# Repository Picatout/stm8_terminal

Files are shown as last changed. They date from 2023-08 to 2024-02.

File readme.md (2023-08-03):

# STM8 terminal 

Un terminal ASCII réalisé sur une carte NUCLEO-S207K8

*   Affichage 62 caractères par ligne, 25 lignes 
*   Clavier PS/2 
*   TVout NTSC. 
*   interface UART niveaux 0:5 volts 

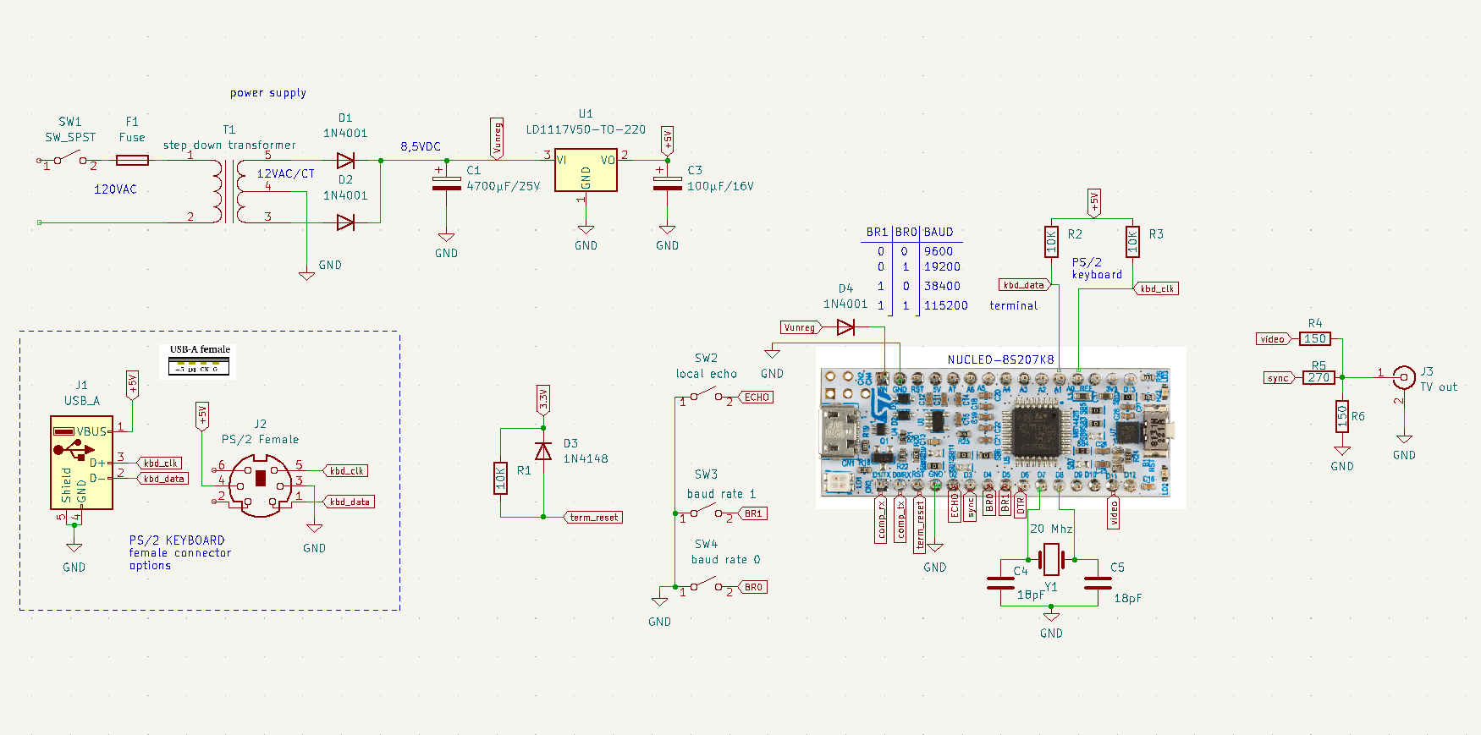
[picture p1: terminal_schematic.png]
schématique


Ce terminal a été créé pour le projet [POMME-I](https://github.com/Picatout/pomme-I).

Les 2 cartes NUCLEO-8S207K8 communique entre elle via le UART. Voir la schématique complète du projet [POMME-I](https://github.com/Picatout/pomme-I) sur le déppôt github de ce dernier. 

## Quand il faut compter les cycles machines.

Sortir 40 caractères par ligne avec un MCU fonctionnant à 20Mhz en utilisant le protocole NTSC n'a pa été évident. Il n'y avait tout simplement pas suffisamment de temps pour utiliser des compteurs avec boucle. Le temps d'affichage d'une ligne de balayage NTSC est de 52µsec. 1 cycle cpu à 20Mhz dure 50nsec on dispose donc d'un maximum de 1040 cycles pour afficher les 40 caractères ce qui donne 26 cycles cpu par caractère.

Après plusieurs expérimentation avec le périphérique SPI qui ne donnait pas de résultat satisfaisant j'ai abandonné le SPI. Pour y parvenir j'ai fait 2 choses. 

1. Le tampon video **video_buffer** ne contient pas les caractères à afficher mais l'adresse du caractère dans la table **font_6x8**. Ainsi il n'y a pas de cycle perdu pour faire le calcul de l'adresse du caractère pendant l'affichage. C'est la routine **tv_putc** qui fait le travail. 

1. Pour sortir les pixels vidéos il faut sérialiser les pixels représentant le caractère. Faire ça en sorftware prend 14 cycles cpu avec la macro  **_shift_out_char** du fichier [tvout.asm](tvout.asm).
La macro **_shift_out_scan_line** prend 20 cycles au total en incluant **_shift_out_char**. Si on fait le calcul pour 40 caractères ça fait 800 cycles soit 40µsec. Bien en déça des 52µsec allouée. Ça c'est selon les cycles machines fournis par le manufacturier du STM8 mais en pratique la durée mesurée à l'oscilloscope est de 51.2µsec. C'est serré! Tellement serré que je ne pouvait utiliser des boucles avec compteurs. Pour arriver à ce temps j'ai du dérouler la macro 40 fois. 

# Où sont passés ces cycles CPU. 

Je me suis mis à réfléchir à cette différence entre le nombre de cycles CPU selon ce que je mesure à l'oscilloscope le temps d'éxécution par caractère serait de 51.2µsec/50nsec=1024/40=25.6 cycles au lieu de 20 cycles. 5.6 de plus. Donc je me demandais où étaient passés ces cycles? Je me suis dit que le fait de lire l'octet dans la table font_6x8 entre en concurrence avec la lecture des instructions machine. STM8 est une architecture Harvard. Ça signigit que le bus d'instruction est séparé du bus de données. Cette architecture a étée conçue pour améliorer la vitesse d'exécution des instructions puisque celle-ci n'ont pas à partager l'accès mémoire avec les données. Je me suis donc dit que si je copiais la table [font_6x8](font.asm) dans la mémoire RAM ce conflit d'accès serait éliminé et que l'exécution serait plus rapide. 

J'ai fait le test et c'est bien le cas, sauf qu'il n'y a qu'un seul cycle machine par caractère de récupéré. L'affichage des 40 caractères avec la police en mémoire RAM prend 49.2µsec soit 2µsec de moins ce qui correspond une fois le calcul fait à 1 cycle par caractère. Il y a donc encore 4.6 cycles manquant. 

Pour comprendre cette différence il faut lire le chapitre 5 du manuel de progammation  [PM0044](https://www.st.com/content/ccc/resource/technical/document/programming_manual/43/24/13/9a/89/df/45/ed/CD00161709.pdf/files/CD00161709.pdf/jcr:content/translations/en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). La section 5.4 et la table 3 nous donnes un bel exemple. Selon le nombre de cycles données dans la description de chaque instruction: 

1.  LDW X,[$50.w] ; 5 cycles 
1.  ADDW X,#20   ; 2 cycles 
1.  LD A,[$300].w ; 4 cycles 

On obtient un total de **11 cycles**. mais dans la table 3 on voit qu'en fait il en faut **12**. 

Donc en conclusion le pipelining permet d'accélérer l'exécution des instructions sauf qu'il n'est plus possible de se fier au nombre de cycles donnés dans la description de chaque instruction pour calculer le temps d'exécution d'une séquence d'instructions, comme c'est le cas pour un mcu PIC 16Fxxxx. 

### 2023-07-17

L'intégration du **STM8_terminal** avec l'ordinateur **POMME-I** a nécessité des modifications aux 2 projets. Durant certaines opérations du terminal ce dernier perdait des caractères envoyés par l'ordinateur. Le problème a été corrigé par l'ajout d'un contrôle de flux matériel appellé **DTR** pour *Data Terminal Ready*. l'ordinateur n'envoie des caractères au terminal que lorsque ce signal est à **0** volt.

### 2023-07-05 

* Modification au circuit du terminal pour ajouter des commutateurs pour la sélection d'options utilisateur.

    * **SW3** sert à sélectionner un écho local lorsqu'il est à **1** 
    * **SW4** et **SW5** permettent de sélectionner un BAUD rate pour  le UART.

  SW4|SW5|BAUD 
    -|-|-
    0|0| 9600
    0|1| 19200
    1|0| 38400
    1|1| 115200

Si les commutateurs ne sont pas installés par défaut les broches sont toutes à **1** à travers les résistances *pull up* MCU, donc il y a écho local et le BAUD est à 115200.

Les commautateurs sont lu lors de l'initialisation et toute modification de leur position requiert un redémarrage du MCU pour que la nouvelle configuration prenne effet.

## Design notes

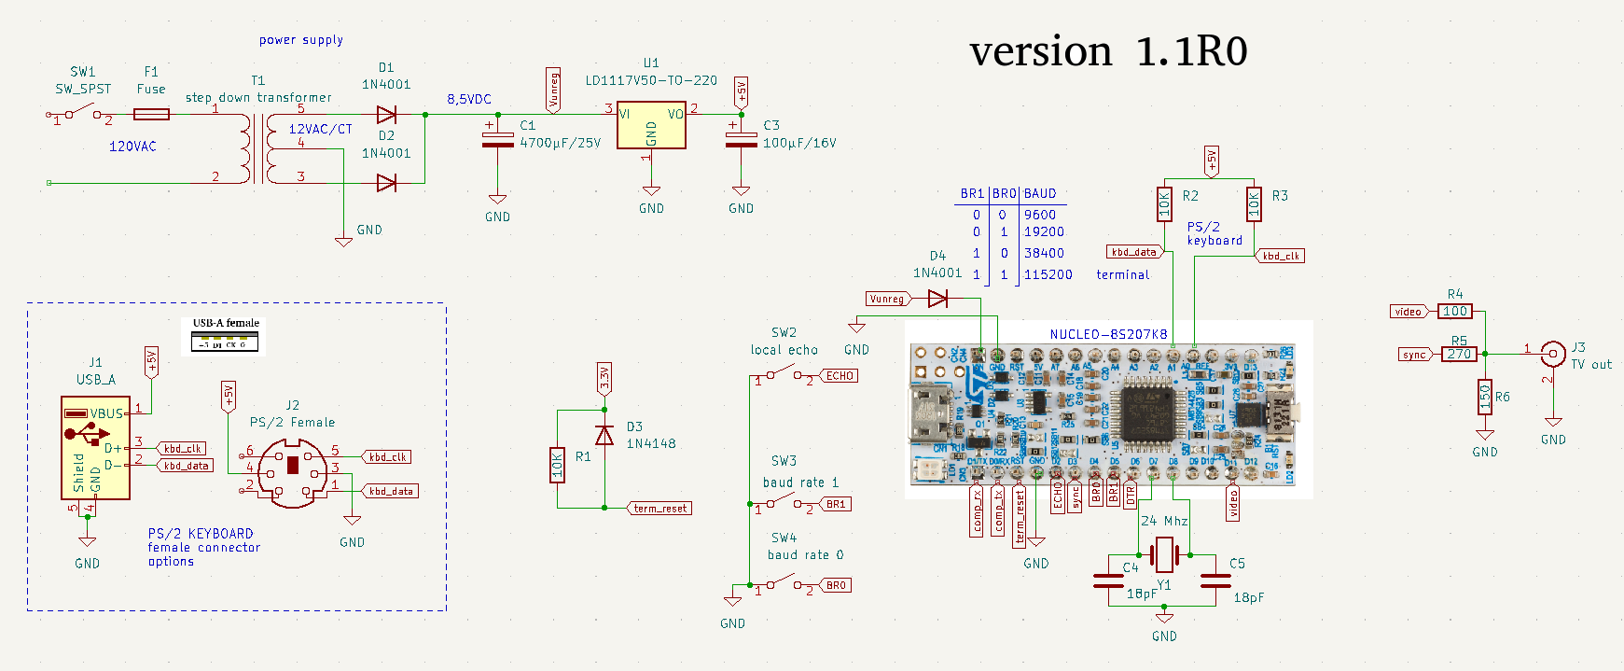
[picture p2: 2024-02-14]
terminal_schematic_v1.1r0.png

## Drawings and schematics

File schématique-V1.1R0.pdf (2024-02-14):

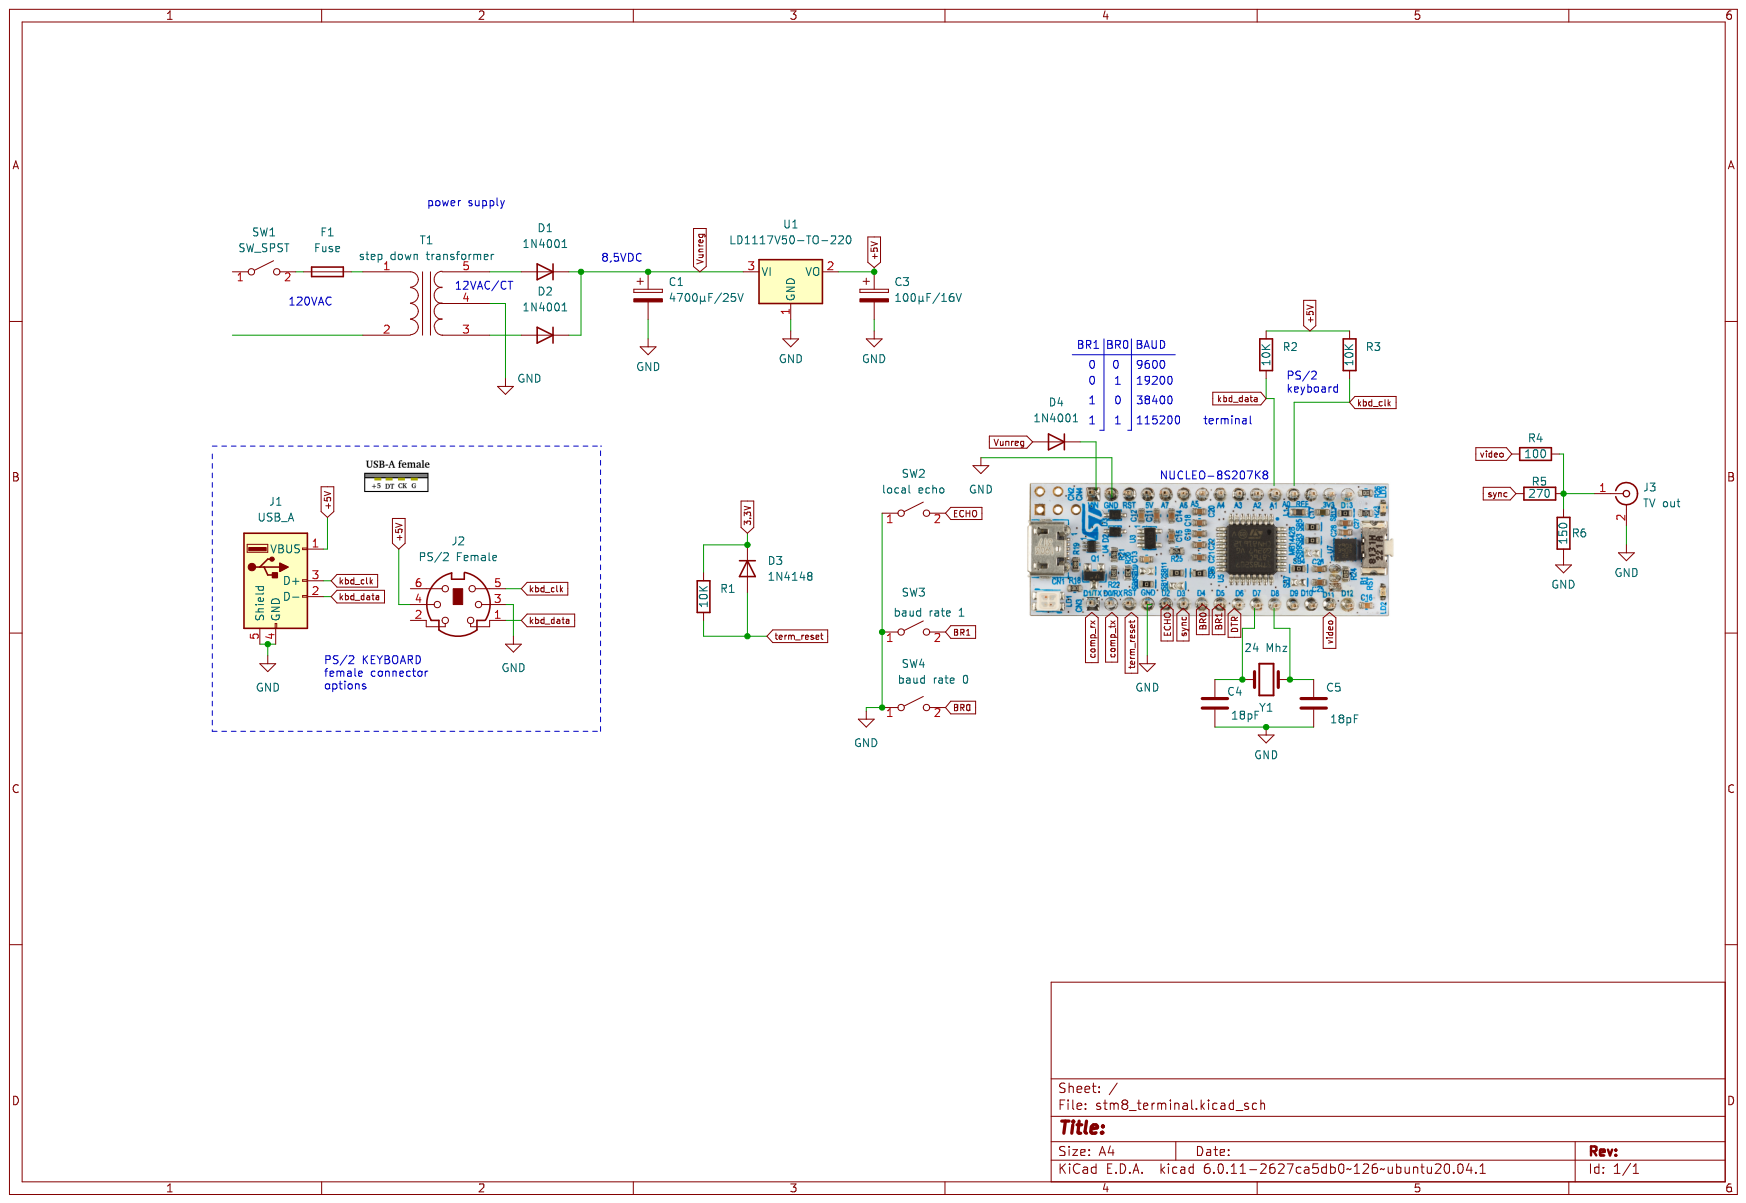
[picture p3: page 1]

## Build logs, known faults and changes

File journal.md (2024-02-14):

### 2024-02-14 

* Mise à jour version vers **V1.1R0**. 

* Modificaction au circuit. 
    1. Test ave crystal de 24Mhz, permet d'afficher 75 caractères par ligne. 
    1. Réduction de la valeur de la résistance **R4** à 100 ohm. 

* Simplifié routine **uart_init** dans [uart.asm](uart.asm).

### 2024-02-09 

* VERSIION **V1.0R15**

* Ajout de la routine **wait_state** pour reprogrammer **OPT7** car le cristal est à 20 Mhz il faut ajouté un wait state pour l'accès à la mémoire FLASH.

### 2023-12-30 

* L'interruption du TIMER4 utilisé pour contrôler le clignotement du curseur texte faisait trop d'interférence dans l'affichage vidéo. J'ai donc modifié le code qui maintenant utilise l'interruption du TIMER1 overflow pour contrôler le clignotement du curseur. 

### 2023-08-08

* Tag V1.0R13 

* Corrigé bogue perte de caractères lors d'un défilement vers le haut.

* Réécriture de la routie *tv_clear_line*. 

* Réécriture de *tv_cls**. Bloqué signal DTR pendant cette opération pour éliminer la perte de caractères en réception uart.

### 2023-08-06

* Corrigé bogue avec **CTRL+lettre** qui ne fonctionnait pas lorsque la touche Verr. Maj. était activée.

### 2023-08-05 

* V1.0R12 
    * Corrigé bogue **CTRL_lettre** ne fonctionnait pas lorsque le **verr.Maj** était activé.

* Modifié l'interface clavier pour que l'hôte puisse envoyer une commande au clavier afin de contrôler l'état des LEDs **Maj. lock** **Num. lock**.

### 2023-08-04

* Modifié le caractère soulignement dans le fichier [font.asm](font.asm).

### 2023-08-02

* V1.0R10 

* Ajout de la commande ANSI  **ESC[6n** qui renvoie la position du curseur sous la forme: **ESC[n;mR**

* Ajout de la commande d'application **ESC_V** pour demander au terminal d'imprimer la version de son firwmare.

### 2023-07-31

* V1.0R9  Ajout de la commande ANSI 
    * **ESC_ C** qui retourne le caractère à la position du curseur.

* Ajout des séquences de contrôle ANSI suivantes:
    * **ESC[ s**  pour sauvegarder la position actuelle du curseur.
    * **ESC[ u**  pour restaurer la position du curseur sauvegardée avec **ESC[ s**.

### 2023-07-29

* Ajout des séquences de contrôle ANSI suivantes:
    * ESC[ n A  déplace le curseur de *n* lignes vers le haut.
    * ESC[ n B  déplace le curseur de *n* lignes vers le bas.
    * ESC[ n C  déplace le curseur de *n* colonnes vers la droite.
    * ESC[ n D  déplace le curseur de *n' colonnes veres la gauche. 

Pour toutes ces commandes la valeur par défaut de *n' est **1**. Si le curseur est déjà à la limite la commande est ignorée.    

### 2023-07-22

* Révision 6 

* Modifié [tv_term.asm](tv_term.asm) pour que le caractère sous le curseur soit préservé.

* Modification à la routine *process_csi* du fichier [tv_term.asm](tv_term.asm). Le problème est le suivant, à l'interne les valeurs de position du curseur son comptée à partir de zéro alors que la commande **LOCATE** de **POMME BASIC** compte à partir de **1** comme les commandes ANSI. Il faut donc décrémenter la valeur des paramètres avant de les appliquer. Je n'avais pas tenu compte de ça dans la première écriture de la routine.

### 2023-07-21 

* Ajout des séquences de contrôle suivantes:
    * **ESC [ Pn G**  pour positionné le curseur sur la colonne **Pn** {1..62} 
    * **ESC [ Pn d**  pour positionner le curseur sur la ligne **Pn** {1..25}
    * **ESC [ Pn ; Pm H** pour positionner le curseur à la ligne **Pn** et la colonne **Pm**.

### 2023-07-17 

* L'intégration du **STM8_terminal** avec l'ordinateur **POMME-I** a nécessité des modifications aux 2 projets. Durant certaines opérations du terminal ce dernier perdait des caractères envoyés par l'ordinateur. Le problème a été corrigé par l'ajout d'un contrôle de flux matériel appellé **DTR** pour *Data Terminal Ready*. l'ordinateur n'envoie des caractères au terminal que lorsque ce signal est à **0** volt.

* Corrigé bogue dans routine *if_shifted* du fichier [ps2.asm](ps2.asm).

* Le terminal n'était pas assez rapide pour capturer tous les caractères reçus du UART. 
    * vitesse du UART réduite à 38400BAUD 
    * Ajout d'une sortie **DTR** sur la broche **D6** 
    * Augmentation de la file du UART à 64 charactères.
    * Augmentation de la file des scan codes à 16 octets.
    * mise à jour révision vers V1.0R2 
    
### 2023-07-10

* Nouvelle tentative d'urtiliser le périphérique SPI dans tvout.asm
    * Succès, même que le nombre de caractères affichable par ligne est passé à 64.
    * Les caractères s'affichent plus nettement, intensité plus régulière.

### 2023-07-05

* Modification de *uart_init* pour lire les switches SW4 et SW5 pour déterminer le BAUD requis.

* Modification de la routine *ntsc_init* pour copier la table *font_6x8* dans la RAM et vérifier l'état de SW3 pour l'écho local.

* Modification au circuit du terminal par l'ajout de commutateurs externes pour les options.

    * **SW3** sélection de l'écho local. 
        **0** pas d'écho locale 
        **1** échoe locale 

    * **SW5** et **SW5** sélection du BAUD rate du UART.

    SW4|SW5|BAUD 
    -|-|-
    0|0| 9600
    0|1| 19200
    1|0| 38400
    1|1| 115200

* Continuation du travail sur [ps2.asm](ps2.asm). 
    * installation de la police de caractères [font_6x8](font.asm) en mémoire RAM. Ceci permet de sauver 2µsec par scan line dans l'interruption d'affichage vidéo **ntsc_video_interrupt**.

    * Ajout du traitement pour les altérations de caractères du aux touches **CTRL** et **ALT**. Les touches de gauche et de droite sont traitées de la même façon.

    * Ajout de la commande **CTLR+E** pour commuter (toggle) l'écho local sur stm8_terminal. 

* mise à jour du [readme.md](readme.md).

### 2023-07-04

* Avancement du travail sur [ps2.asm](ps2.asm), traite les touches **Ver. maj.** et  **Maj.** correctement. Reste à implémentater le traitement des touches **CTRL** et **ALT**. 

* Travail sur [ps2.asm](ps2.asm).

### 2023-07-03 

* Début du travail sur [ps2.asm](ps2.asm).

* Corrigé bogue dans *tv_cursor_right*. 

* Corrigé bogue dans *tv_disable_cursor*. 

*  Travail sur [tvout.asm](tvout.asm), j'ai trouvé une méthode pour permettre d'afficher 40 caractères par ligne. Le tampon vidéo contient l'adresse du caractère dans la table de la police, plutôt que le caractère lui-même. De cette façon cette adresse n'a pas besoin d'être calculé au moment de l'affichage. On sauve ainsi plusieurs cycles machines par caractère. De plus l'espace entre chaque caractère est plus étroit ce qui améliore l'apparence.

### 2023-07-02

* Travail sur [tvout.asm](tvout.asm), amélioration au prix de la réduction du nombre de caractère par ligne 34 au lieu de 40. 

 * Abandon de l'utilisation du périphérique SPI. 

 * les pixels sont sérialisés avec déroulement des boucles en utilisant des macros. C'est la seule façon de réduire le nombre de cycles machine par pixel. Avec cette méthode j'obtient 28 cycles par pixel. 7 pixels par caractères sont envoyés.

### 2023-07-01

 * Ajout de [tv_term.asm](tv_term.asm). Encore un problème avec la qualité de l'affichage sur la tV.

 * Travail sur [tvout.asm](tvout.asm), maintenant affiche les caractères presque correctement sauf qu'il en affiche 41 par ligne au lieu d 40. 
 l'affichage ne semble pas tenir compte des scan_lines!!.

### 2023-06-29

* Travail sur [tvout.asm](tvout.asm)

### 2023-06-28

* Démarrage du projet.

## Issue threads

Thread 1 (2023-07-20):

Le terminal ne s'initialise pas toujours correctement

Picatout, 2023-07-20:
Lors de la mise sous tension de l'ordinateur le terminal ne s'initialise pas toujours et le signal vidéo demeure indisponible même lorsqu'on fait un reset de la carte NUCLEO avec le bouton à cet effet sur la carte.

Picatout, 2023-07-21:
bogue corrigé

Closed 2023-07-21.

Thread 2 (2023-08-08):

Le terminal perd des caractères lors d'un défilement vers le haut

Picatout, 2023-08-08:
lorsque le terminal reçoit un flue continue de caractères il perd des caractères lorsqu'il arrive en bas de l'écran et doit faire un défilement vers le haut (scroll up).

Picatout, 2023-08-09:
J'ai fait des modifications au terminal qui ont réduit les pertes de caractères en désactivant le signal DTR lorsque le terminal efface l'écran, i.e. routine tv_cls. Maintenant lorsque je fait un CTRL+X pour redémarrer l'ordinateur la message de présentation du moniteur n'est plus perdu mais je de suis pas certain d'avoir résolu le problème à 100%.  J'attend donc avant de conclure.

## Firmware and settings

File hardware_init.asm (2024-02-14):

;;
; Copyright Jacques Deschênes 2023  
; This file is part of stm8_terminal 
;
;     stm8_terminal is free software: you can redistribute it and/or modify
;     it under the terms of the GNU General Public License as published by
;     the Free Software Foundation, either version 3 of the License, or
;     (at your option) any later version.
;
;     stm8_terminal is distributed in the hope that it will be useful,
;     but WITHOUT ANY WARRANTY; without even the implied warranty of
;     MERCHANTABILITY or FITNESS FOR A PARTICULAR PURPOSE.  See the
;     GNU General Public License for more details.
;
;     You should have received a copy of the GNU General Public License
;     along with stm8_terminal.  If not, see <http://www.gnu.org/licenses/>.
;;

;;;;;;;;;;;;;;;;;;;;;;;;;;;;;;;
;;; hardware initialization
;;;;;;;;;;;;;;;;;;;;;;;;;;;;;; 

;------------------------
; if unified compilation 
; must be first in list 
;-----------------------

    .module HW_INIT 

    .include "config.inc"

STACK_SIZE=128   
;;-----------------------------------
    .area SSEG (ABS)
;; working buffers and stack at end of RAM. 	
;;-----------------------------------
    .org RAM_SIZE-STACK_SIZE
stack_full:: .ds STACK_SIZE   ; control stack full 
stack_unf: ; stack underflow ; RAM end +1 -> 0x1800


;;--------------------------------------
    .area HOME 
;; interrupt vector table at 0x8000
;;--------------------------------------

    int cold_start			; RESET vector 
	int NonHandledInterrupt ; trap instruction 
	int NonHandledInterrupt ;int0 TLI   external top level interrupt
	int NonHandledInterrupt ;int1 AWU   auto wake up from halt
	int NonHandledInterrupt ;int2 CLK   clock controller
	int NonHandledInterrupt ;int3 EXTI0 gpio A external interrupts
	int ps2_intr_handler    ;int4 EXTI1 gpio B external interrupts
	int NonHandledInterrupt ;int5 EXTI2 gpio C external interrupts
	int NonHandledInterrupt ;int6 EXTI3 gpio D external interrupts
	int NonHandledInterrupt ;int7 EXTI4 gpio E external interrupts
	int NonHandledInterrupt ;int8 beCAN RX interrupt
	int NonHandledInterrupt ;int9 beCAN TX/ER/SC interrupt
	int NonHandledInterrupt ;int10 SPI End of transfer
	int ntsc_sync_interrupt ;int11 TIM1 update/overflow/underflow/trigger/break
	int ntsc_video_interrupt ; int12 TIM1 capture/compare
	int NonHandledInterrupt ;int13 TIM2 update /overflow
	int NonHandledInterrupt ;int14 TIM2 capture/compare
	int NonHandledInterrupt ;int15 TIM3 Update/overflow
	int NonHandledInterrupt ;int16 TIM3 Capture/compare
	int NonHandledInterrupt ;int17 UART1 TX completed
.if NUCLEO_8S208RB  
	int UartRxHandler		;int18 UART1 RX full 
.else 
	int NonHandledInterrupt ;int18 UART1 RX full 
.endif 
	int NonHandledInterrupt ;int19 I2C 
	int NonHandledInterrupt ;int20 UART3 TX completed
.if NUCLEO_8S207K8  
	int UartRxHandler 		;int21 UART3 RX full
.else 
	int NonHandledInterrupt ;int21 UART3 RX full
.endif 
	int NonHandledInterrupt ;int22 ADC2 end of conversion
	int NonHandledInterrupt	;int23 TIM4 update/overflow ; use to blink tv cursor 
	int NonHandledInterrupt ;int24 flash writing EOP/WR_PG_DIS
	int NonHandledInterrupt ;int25  not used
	int NonHandledInterrupt ;int26  not used
	int NonHandledInterrupt ;int27  not used
	int NonHandledInterrupt ;int28  not used
	int NonHandledInterrupt ;int29  not used


KERNEL_VAR_ORG=4
;--------------------------------------
    .area DATA (ABS)
	.org KERNEL_VAR_ORG 
;--------------------------------------	

; keep the following 3 variables in this order 
acc16:: .blkb 1 ; 16 bits accumulator, acc24 high-byte
acc8::  .blkb 1 ;  8 bits accumulator, acc24 low-byte  
ptr16::  .blkb 1 ; 16 bits pointer , farptr high-byte 
ptr8:   .blkb 1 ; 8 bits pointer, farptr low-byte  
flags:: .blkb 1 ; various boolean flags

; keyboard variables
; received scan codes queue 
SC_QUEUE_SIZE=32  
sc_queue: .blkb SC_QUEUE_SIZE ; scan codes queue 
sc_qhead: .blkb 1  ; sc_queue head index 
sc_qtail: .blkb 1  ; sc_queue tail index 
in_byte:  .blkb 1 ; shift in byte buffer 
parity:   .blkb 1 ; parity bit 
sc_rx_flags: .blkb 1 ; receive code flags 
sc_rx_phase: .blkb 1 ; scan code receive phase 
;; transmission to keyboard variables 
out_byte: .blkb 1 ; send byte to keyboard 
tx_bit_cntr: .blkb 1 ;bit counter for out_byte shifting.
tx_phase: .blkb 1 ; sending to keyboard phases 
tx_parity: .blkb 1 ; parity counter  

KBD_QUEUE_SIZE=16
kbd_queue: .blkb KBD_QUEUE_SIZE 
kbd_queue_head: .blkb 1 
kbd_queue_tail: .blkb 1 
kbd_state: .blkb 1 ; keyboard state flags 

; tvout variables 
ntsc_flags: .blkb 1 
ntsc_phase: .blkb 1 ; 
scan_line: .blkw 1 ; video lines {0..262} 
font_addr: .blkw 1 ; font table address 

; tv terminal variables 
cursor_x: .blkb 1 
cursor_y: .blkb 1 
cursor_delay: .blkb 1 ;  20/60 sec delay 
char_under: .blkb 1 ; character under cursor 
char_cursor: .blkb 1 ; character used for cursor 
saved_cx: .blkb 1 ; saved cursor position
saved_cy: .blkb 1 ; restored cursor position
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

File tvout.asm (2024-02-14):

;
; Copyright Jacques Deschênes 2023 
; This file is part of stm8_terminal 
;
;     stm8_terminal is free software: you can redistribute it and/or modify
;     it under the terms of the GNU General Public License as published by
;     the Free Software Foundation, either version 3 of the License, or
;     (at your option) any later version.
;
;     stm8_terminal is distributed in the hope that it will be useful,
;     but WITHOUT ANY WARRANTY; without even the implied warranty of
;     MERCHANTABILITY or FITNESS FOR A PARTICULAR PURPOSE.  See the
;     GNU General Public License for more details.
;
;     You should have received a copy of the GNU General Public License
;     along with stm8_terminal.  If not, see <http://www.gnu.org/licenses/>.
;;

DTR_ODR=PC_ODR 
DTR_DDR=PC_DDR 
DTR_CR1=PC_CR1 
DTR_CR2=PC_CR2
DTR_PIN=3 ; DTR_PIN on PC:3 

.if MAX_FREQ 
CHAR_PER_LINE=75 ; xtal 24Mhz 
.else 
CHAR_PER_LINE=62  ; xtal 20Mhz 
.endif 

LINE_PER_SCREEN=25 
VISIBLE_SCAN_LINES=200 

; values based on 20 Mhz crystal

FR_HORZ=15734
HLINE=(FMSTR*1000000/FR_HORZ-1); horizontal line duration 
HALF_LINE=HLINE/2 ; half-line during sync. 
EPULSE=47 ; pulse width during pre and post equalization
VPULSE=546 ; pulse width during vertical sync. 
HPULSE=94 ; 4.7µSec horizontal line sync pulse width. 
LINE_DELAY=(160) 

; ntsc synchro phases 
PH_VSYNC=0 
PH_PRE_VIDEO=1
PH_VIDEO=2 
PH_POST_VIDEO=3 

FIRST_VIDEO_LINE=50 
VIDEO_LINES=200 

;ntsc flags 
F_EVEN=0 ; odd/even field flag 
F_CURSOR=1 ; tv cursor active 
F_CUR_VISI=2 ; tv cursor state, 1 visible 
F_LECHO=3 ; local echo 
F_VIDEO=4 ; enable video output 
F_NO_DTR=5 ; forbid DTR during some operation
F_CUR_TOGGLE=6 ; time to toggle cursor state 

;-------------------------------
    .area CODE 
;------------------------------

;------------------------------
; initialize TIMER1 for 
; NTSC synchronisation 
; signal 
;------------------------------
ntsc_init:
    _clrz ntsc_flags 
    _clrz ntsc_phase 
; set MOSI pin as output high-speed push-pull 
    bset PC_DDR,#6 
    bres PC_ODR,#6
    bset PC_CR1,#6
    bset PC_CR2,#6
; set PC:3 as DTR output 
    bset DTR_CR1,#DTR_PIN ; push-pull output 
    bset DTR_DDR,#DTR_PIN 
    bres DTR_ODR,#DTR_PIN      
    clr SPI_SR 
    mov SPI_CR1,#(1<<SPI_CR1_SPE)|(1<<SPI_CR1_MSTR) 
    clr SPI_DR 
; initialize timer1 for pwm
; generate NTSC sync signal  
    mov TIM1_IER,#1 ; UIE set 
    bset TIM1_CR1,#TIM1_CR1_ARPE ; auto preload enabled 
    mov TIM1_CCMR1,#(7<<TIM1_CCMR1_OCMODE)  |(1<<TIM1_CCMR1_OC1PE)
    bset TIM1_CCER1,#0
    bset TIM1_BKR,#7
; use channel 2 for video stream trigger 
; set pixel out delay   
    mov TIM1_CCMR2,#(6<<TIM1_CCMR2_OCMODE) 
    mov TIM1_CCR2H,#LINE_DELAY>>8 
    mov TIM1_CCR2L,#LINE_DELAY&0xFF
;    bset TIM1_CCER1,#0      
; begin with PH_PRE_EQU odd field 
    _clrz ntsc_phase 
    mov TIM1_ARRH,#HLINE>>8
    mov TIM1_ARRL,#HLINE&0XFF
    mov TIM1_CCR1H,#HPULSE>>8 
    mov TIM1_CCR1L,#HPULSE&0XFF
    call copy_font
; test for local echo option
    btjf OPT_ECHO_PORT,#OPT_ECHO_BIT,1$
    bset ntsc_flags,#F_LECHO
1$:    
    call tv_cls 
    call tv_enable_cursor
    bset TIM1_CR1,#TIM1_CR1_CEN 
    ld a,#CURSOR_DELAY
    _straz cursor_delay
    ld a,#1
    call video_on_off 
    ret 

;--------------------
; enable|disable 
; video output 
; input:
;   A    0->off 
;        1->on
;--------------------
video_on_off:
    tnz a 
    jreq 1$ 
; enable video 
    bset ntsc_flags,#F_VIDEO 
    bset ntsc_flags,#F_CURSOR
    bset TIM1_IER,#TIM1_IER_UIE 
    ret     
1$: ; disable video 
    bres ntsc_flags,#F_VIDEO 
    bres ntsc_flags,#F_CURSOR
    bres TIM1_IER,#TIM1_IER_CC2IE 
    bset TIM1_IER,#TIM1_IER_UIE 
    ret 


;----------------------------------
; copying font table to RAM 
; save 2µsec per scan line display 
; in ntsc_video_interrupt
;----------------------------------
copy_font:
	ldw x,#font_end 
	subw x,#font_6x8 
	_strxz acc16 
	ldw x,#256 
	ldw y,#font_6x8 
	call move 
	ldw x,#256 
	_strxz font_addr 
    ret 

;-------------------------------
; TIMER1 update interrupt handler 
; interrupt happend at end 
; of each phase and and pwm 
; is set for next phase 
;-------------------------------
ntsc_sync_interrupt:
    clr TIM1_SR1 
    _ldxz scan_line 
    incw x 
    _strxz scan_line 
    _ldaz ntsc_phase 
    cp a,#PH_VSYNC  
    jrne test_pre_video 
    cpw x,#1 
    jrne  1$ 
    mov TIM1_ARRH,#HALF_LINE>>8 
    mov TIM1_ARRL,#HALF_LINE & 0xff 
    mov TIM1_CCR1H,#EPULSE>>8 
    mov TIM1_CCR1L,#EPULSE&0xff 
    jp sync_exit 
1$: cpw x,#7 
    jrne 2$ 
    mov TIM1_CCR1H,#VPULSE>>8 
    mov TIM1_CCR1L,#VPULSE&0xff 
    jp sync_exit 
2$:
    cpw x,#13 
    jrne 3$ 
    mov TIM1_CCR1H,#EPULSE>>8 
    mov TIM1_CCR1L,#EPULSE&0xff 
    jp sync_exit 
3$: 
    cpw x,#18 
    jrne 5$ 
    btjt ntsc_flags,#F_EVEN,sync_exit 
4$:
    mov TIM1_ARRH,#HLINE>>8 
    mov TIM1_ARRL,#HLINE & 0xff 
    mov TIM1_CCR1H,#HPULSE>>8 
    mov TIM1_CCR1L,#HPULSE&0xff 
    inc a 
    jp sync_exit 
5$: 
    cpw x,#19 
    jreq 4$ 
    jra sync_exit 
test_pre_video:
    cp a,#PH_PRE_VIDEO 
    jrne post_video  
    cpw x,#20 
    jrne 2$
    call cursor_blink_handler
    jra sync_exit
2$:
    cpw x,#FIRST_VIDEO_LINE
    jrne sync_exit 
    inc a 
    btjf ntsc_flags,#F_VIDEO,sync_exit
    bres TIM1_IER,#TIM1_IER_UIE 
    bset TIM1_IER,#TIM1_IER_CC2IE
    jra sync_exit
post_video:
    cpw x,#271
    jrne 2$ 
    btjf ntsc_flags,#F_EVEN,#3$  
    jra sync_exit  
2$: 
    cpw x,#272 
    jrne sync_exit 
    mov TIM1_ARRH,#HALF_LINE>>8
    mov TIM1_ARRL,#HALF_LINE & 0xff 
3$: ;field end     
    clr a 
    clrw x 
    _strxz scan_line
    bcpl ntsc_flags,#F_EVEN
sync_exit:
    _straz ntsc_phase
    iret
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

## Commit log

2023-07-01 Amélioration de tvouat.asm mais toujours pas satisfaisant, affiche 41 charactères par lignes./build.sh s207 flash
2023-07-02 Travail sur tvout.asm et ajout de tv_term.asm
2023-07-03 Travail sur tvout.asm, amélioration au prix de la réduction du nombre de caractère par ligne 34 au lieu de 40
2023-07-05 Avancement du travial sur [ps2.asm](ps2.asm), traite les touches **Ver. maj.** et **Maj.** correctement. Reste à implémentater le traitement des touches **CTRL** et **ALT**.
    [hardware_init.asm, ps2.asm, tvout.asm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]
2023-07-05 Ajout des altérations de touches par CTRL et ALT
2023-07-05 ajout de la commande CTLR+E pour activer l'écho local sur le terminal
2023-07-06 Modification matérielle et logicielle pour par l'ajout de commutateurs pour la sélection d'options utilisateur
2023-07-06 Ajout de fichiers oubliés au git
2023-07-10 Modification de tvout.asm avec l'utilisatation du SPI pour sérialiser les pixels le terminal affiche maintenant 64 caractères par ligne.
2023-07-17 Augmentation des files uart et clavier mise à jour révision V1.0R2
2023-07-21 correction bogue initialisation instable
    [hardware_init.asm, tvout.asm]
2023-07-22 Ajout du traitement des séquence ANSI pour le positionnement du curseur, V1.0R5
2023-07-22 Modification pour que le caractère sous le curseur soit préservé, rendu nécessaire par l'ajout de LOCATE dans le POMME BASIC
2023-07-29 Ajout des séquences ANSI ESC[ n A ESC[ n B ESC[ n C ESC[ n D pour les déplacements relatifs du curseur
2023-08-01 V1.0R8 ajout des commandes ANSI ESC [ s pour sauvegarder la position du curseur ESC [ u pour restaurer la position du curseur.
2023-08-01 Ajout de la commande d'application ESC_C
2023-08-03 V1.0R10 Ajout de la commande ANSI **ESC[6n** pour connaître la position du curseur Ajout de la commande d'appliation **ESC_V** pour imprimer la version du firwmare du terminal
2023-08-06 Modififié ps2.asm pour que l'hôte puisse envoyer des commandes au clavier
2023-08-07 Corrigé bogue CTRL+lettre ne fonctionnait pas lorsque la toucher verr. maj. était activée
    [ps2.asm]
2023-08-09 V1.0R13 Réécriture de tv_cls et tv_clear_line pour réduire la perte de caractères en réception uart
2023-12-30 Amélioration de la sortie vidéo rédution de l'interférence en éliminant l'interruption sur de TIM4
2024-01-01 Ajout du dossier kiCAD
    [stm8_terminal.kicad_pcb, stm8_terminal.kicad_sch]
2024-01-01 Modification à la schématique
    [stm8_terminal.kicad_sch]
2024-02-14 Modification hardware, remplacé cristal pour un 24Mhz permettant d'afficher 75 caractères par ligne. remplacé résistance R4 par 100 ohm modifié routine uart_init et fichier config.inc
2024-02-14 mise à jour schématique vers V1.1R0
    [stm8_terminal.kicad_sch]
